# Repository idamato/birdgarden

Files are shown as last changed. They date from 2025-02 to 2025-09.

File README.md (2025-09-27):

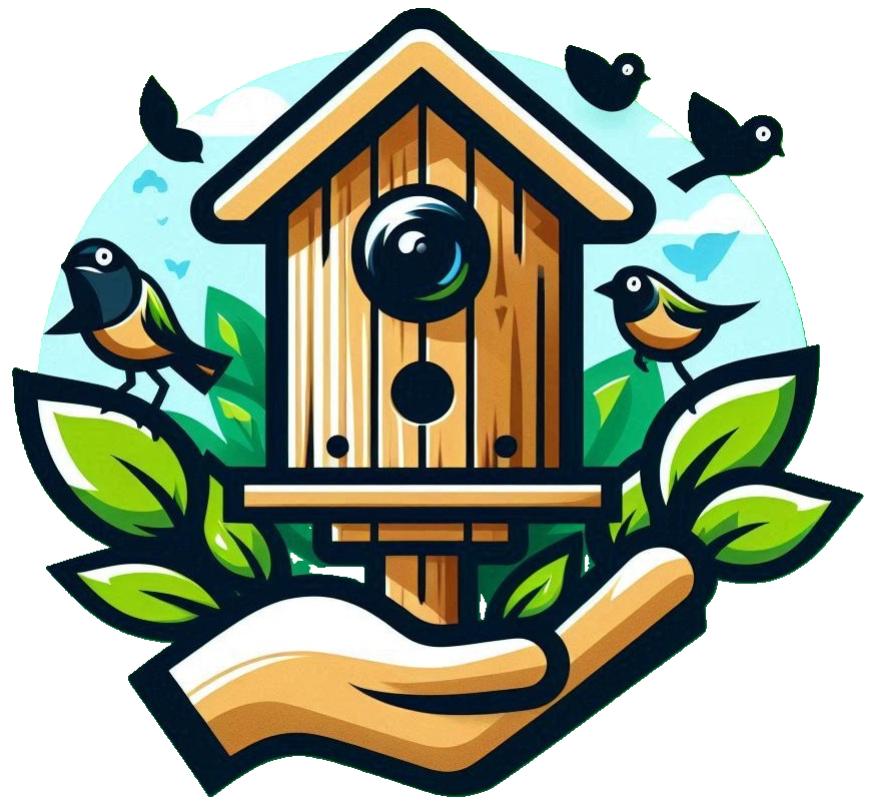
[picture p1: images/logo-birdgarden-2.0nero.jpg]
Birgaren 2.0 Logo


# Birdgarden 2.0

Progetto realizzato a cura dei soci di il faro d'argento APS [www.webradiofaro.it](www.webradiofaro.it)

Il progetto Birdgarden 2.0 mira alla realizzazione di una casetta/nido o mangiatoia per gli uccellini, monitorata attraverso una camera ed un microfono nascosti che metterà a disposizione su internet i dati rilevati, l’audio e le foto scattate nei momenti in cui viene occupata.

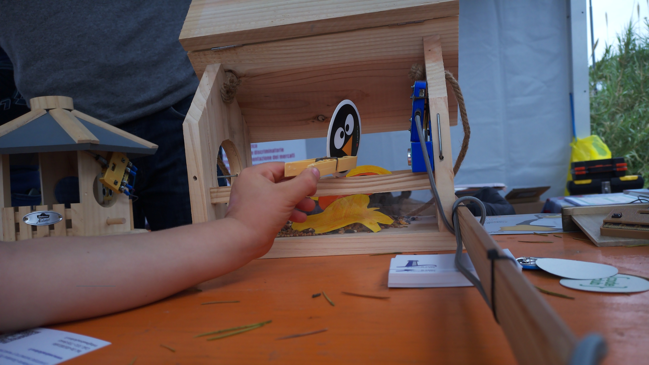
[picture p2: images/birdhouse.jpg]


Per l'inizializzazione del dispositivo al primo utilizzo sono necessarie alcune attività per le quali è necessario collegare al dispositivo un monitor o TV tramite il cavo HDMI ed una tastiera+mouse tramite il cavo USB aggiuntivo.

 In alternativa è possibile configurare il sistema raspberry attraverso una connessione seriale, per mezzo di un cavo del tipo USB-to-SERIAL con chip PL2303, facendo attenzione al fatto che sia utilizzabile con la tensione dei 3V dei GPIO del Raspberry.

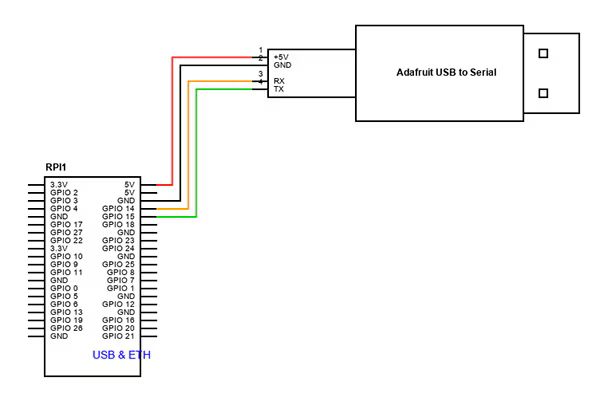
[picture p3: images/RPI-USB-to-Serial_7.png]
RPI-Serial
 

Per il collegamento attraverso la porta seriale è necessario abilitarne l'accesso nel file config.txt inserendo la seguente riga: enable_uart=1

Nelle versioni più recenti del sistema Raspian OS non esiste un utente preconfigurato con cui eseguire il login tuttavia tramie il software Raspberry Pi Imager è possibile definire le principali configurazioni prima ancora del primo avvio, cosa che in questo progetto abbiamo fatto per voi.

Per i sistemi Linux Debian è sufficiente digitare il comando
~~~
sudo apt install rpi-imager
~~~ 

Mentre per Windows si può scaricare l'installer direttamente dal sito [raspberrypi.com](https://www.raspberrypi.com/software/)]

Per il collegamento via seriale abbiamo utilizzato il comando: tio /dev/ttyUSB0, dopo aver verificato che il device ttyUSB0 fosse correttamente associato al cavo USB-to-serial inserito, per mezzo del comando: sudo dmesg, che fornisce le seguenti informazioni:

~~~bash
[ 7849.113480] usb 1-2: new full-speed USB device number 13 using xhci_hcd
[ 7849.240467] usb 1-2: New USB device found, idVendor=067b, idProduct=2303, bcdDevice= 4.00
[ 7849.240514] usb 1-2: New USB device strings: Mfr=1, Product=2, SerialNumber=0
[ 7849.240537] usb 1-2: Product: USB-Serial Controller
[ 7849.240555] usb 1-2: Manufacturer: Prolific Technology Inc.
[ 7849.245418] pl2303 1-2:1.0: pl2303 converter detected
[ 7849.248483] usb 1-2: pl2303 converter now attached to **ttyUSB0**
~~~

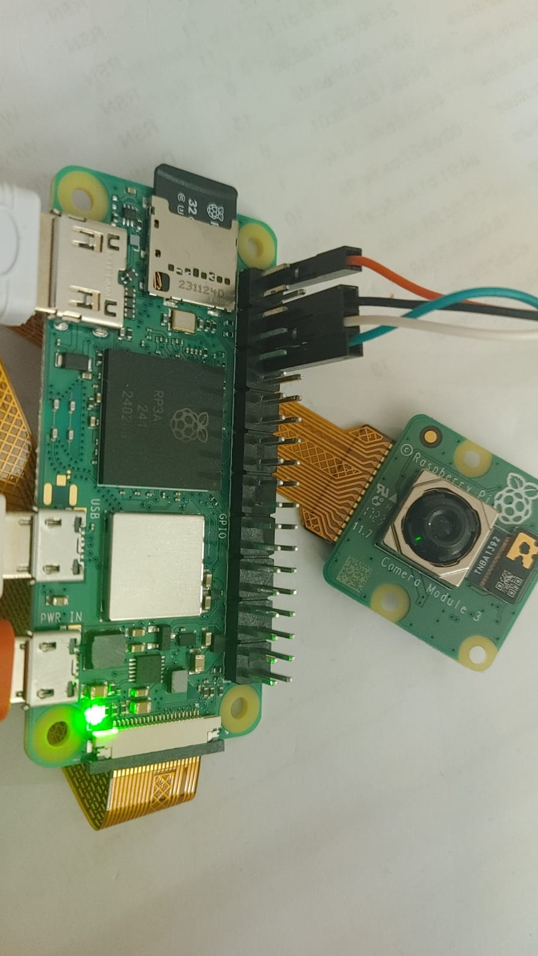
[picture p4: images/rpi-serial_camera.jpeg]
Rpi-Serial-Camera


## Configurazione iniziale

Tenete a mente che durante il primo avvio il sistema opera delle configurazioni automatiche ed esegue anche un riavvio automatico, quindi impiega necessariamente più tempo a partire rispetto ad una normale procedura, come accadrà in seguito. Se tutto è andato a buon fine avrete a video la richiesta di login, oppure il desktop del sistema Raspian OS, se avete installato la versione desktop. In tal caso potrete aprire una finestra terminale per proseguire con le attività di configurazione descritte nel seguito.

Eseguire le operazioni seguenti:

- eseguire il login con username e password impostati (l'importante è che la home directory si chiami /home/ilfarodargento)
- eseguire l’aggiornamento di RPI Os con i comandi:

```bash
$ sudo -s 
$ export DEBIAN_FRONTEND=noninteractive
$ apt update -y \
  && apt upgrade -y \
  && apt full-upgrade -y
```
> [!NOTE] 
> Questo task può durare anche 30 minuti

Terminato l'operazione è consigliato effettuare il riavvio

Procedere all'installazione delle dipendenze

~~~bash
$ sudo apt update && \
  sudo apt install -y python3-picamera2\
                      ffmpeg \
                      git \
                      python3-serial \
~~~

Terminata l'installazione effettuare il clone di questo repository all'interno della RPi

~~~bash
$ git clone https://github.com/idamato/birdgarden/
~~~

e procedere all'installazione

~~~
$ cd birdgarden
$ sudo bash install_rpi.sh
~~~

- modificare username e password e identificativo TAG con la CPUID nel file wordpress_playground.py secondo le indicazioni ricevute al momento dell'adesione al progetto. (Viene creato un account all'interno del portale Birdgarden 2.0 con le credenziali per la pubblicazione delle foto/video dal dispositivo)
- creare il link simbolico al file photo.service di avvio del servizio al boot:
  sudo cp /home/ilfarodargento/birdgarden/photo.service /lib/systemd/system/photo.service ;
  sudo systemctl enable photo.service ;
  sudo systemctl start photo.service (comando per l'avvio manuale) ;
  sudo journalctl --unit=photo.service (per verificare il log delle esecuzioni precedenti)
- configurare il comando a tempo (crontab -e) aggiungendo in fondo la seguente riga:
  - `30 * * * * /home/ilfarodargento/birdgarden/sendphoto.sh >> /home/ilfarodargento/logs/cron.log 2>&1`
- dalla /home/ilfarodargento creare le directory per i log e per le foto da spedire e spedite con: `mkdir logs departures sent`
- per la rotazione dei log installiamo il file di configurazione: `sudo cp birdgarden/birdgarden /etc/logrotate.d/`
- esegure il test del focus della fotocamera sulla vostra installazione eseguendo il comando: `python3 test-camera-focus.py`; tenete presente che se state utilizzando il terminale senza grafica dovrete prima modificare lo script impostando la preview a False.
- collegare anche il dispositivo micro:bit caricandovi il codice `serial_data_logger.py` tramite il sito [Makecode](makecode.microbit.org).
- Se si desidera modificare la configurazione del WiFi si può procedere nel modo seguente: eseguire il comando: `sudo nmtui`, ed abilitare la rete wifi di interesse.

Se si desidera modificare la configurazione del WiFi si può procedere nel modo seguente:
- eseguire il comando: sudo nmtui, ed abilitare la rete wifi di interesse

Ci sono inoltre una serie di aspetti di configurazione che sono stati curati all'interno del portale https://www.webradiofaro.it/birdgarden/ che utilizza Wordpress.
In particolare deve essere creato un utente/ruolo specifico associato al dispositivo in modo che nello stesso portale possano concorrere le pubblicazioni di tutti i dispositivi.
Oltre all'utente deve essere anche creata una chiave applicativa legata all'applicazione Birdgarden e con essa si avranno le credenziali da inserire nello scirpt Python per l'invio dati.

-

# Testing 

>[!WARNING]
Work in progress

Per RPi  ARMv7
```bash
podman run -it  --volume $PWD:/src --platform=linux/arm/7 dtcooper/raspberrypi-os:bookworm
```

Per RPi ARM64

```bash
podman run -it  --volume $PWD:/src --platform=linux/arm64 dtcooper/raspberrypi-os:bookworm
```

e poi 

~~~bash
# cd /src
# bash install_rpi.sh
~~~

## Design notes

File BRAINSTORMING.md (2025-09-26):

This is a brainstorming file where to put your immagination about the possible future evolution of this project.

1) AI adoption
    a) AI hardware selection
    b) AI engine selection
    c) AI training needed?

2) Mesh network configuration

3) Solar panel integration

4) Is it worth to have the Micro:bit out of this project, or there could be some hidden benefits?
    a) How do you think about having Micro:bit as an optional device? Wireless connected via serial-bluethoot to the Raspberry, only to issue command to this one? 
    b) Is it worth to use PIR sensor instead of the SONAR one, and connect it directly to the Raspberry?

5) Are terminal based (text) images possible to inject as AI training? ASCII Art convertion could help reduce the complexity of the AI model and calculations?

6) Ham radio SSTV mode as a new option for sending images
    a) There is a Python module which enable image transformation into wav files
       Some instruction require installation of specific libraries, check inside GitHub repository of every library or software.
       The following may be needed: sudo apt install libgd-dev libmagic-dev
       a.1)
           The generated audio can be sent as a modulated FM signal over the antenna using PiFM 
           git clone https://github.com/dnet/pySSTV
           cd pySSTV ; python3 ./setup.y build ; sudo python3 ./setup.py install
           cd <where images are> ; python3 -m pysstv --mode MartinM2 --resize image.png output.wav 
           an image file of 35Kb result in an audio wav file of about 5.5 Mb.
       a.2) Raspberry pi is able to send FM mofulation as RF via a small antenna connected to the GPIO4
       git clone https://github.com/F5OEO/rpitx
       cd rpitx ; ./install.sh (the compile process somehow fail to compile some programs but we need the pifmrds which is orrectly available)
       reboot
       sudo ./pifmrds -freq 76 -audio /home/ilfarodargento/sent/pettirosso-inverno.wav
    b) per trasmettere a frequenze differenti dalla FM commerciale, come ad esempio a 433 Mhz la procedura è differente:
       si usa imagemagik per trasformare l'immagine in un formato adatto con il comando seguente
       convert <input> -resize '320x256^' -gravity center -extent 320x256 -depth 8 <output>.rgb
       poi si converte il file .rgb in formato .ft con il comando seguente
       pisstv <input>.rgb <output>.ft
       ed infine si avvia la trasmissione alla frequenza desiderata, il range è da pochi kHz fino a 700 Mhz, con il comandi seguente
       sudo rpitx -m RF -i <input>.ft -f <frequency in KHz>
       
...possibile utilizzo anche per le radiosonde che potrebbero inviare immagini
        
script funzionanti:

ilfarodargento@birdgarden:~/birdgarden $ cat encoderMicroFAX.py
from PIL import Image
import numpy as np
import wave
import struct
import math
import serial
import threading
import queue
import time

# Parametri SSTV semplificati
INPUT_IMAGE = "../images/Pettirosso.jpg"
CONVERTED_IMAGE = "../images/microfax_pettirosso.jpg"
OUTPUT_WAVE = "../images/microfax_signora.wav"
WIDTH, HEIGHT = 64, 64
GRAY_MIN, GRAY_MAX = 0, 255
FREQ_MIN, FREQ_MAX = 1500, 2300
PIXEL_DURATION = 0.05
SYNC_FREQ = 1200
SYNC_DURATION = 0.2
EOL_FREQ = 300          # Frequenza speciale fine riga
EOL_DURATION = 0.05     # Durata tono fine riga
SAMPLE_RATE = 44100
samples = 0

# Imposta la connessione seriale
ser_micro = serial.Serial('/dev/ttyACM0', 115200, timeout=1)
if not ser_micro:
    logging.info('microbit not found')

def load_and_convert_image(path):
    img = Image.open(path).convert('L')
    img = img.resize((WIDTH, HEIGHT), Image.NEAREST)
    img.save(CONVERTED_IMAGE)
    return np.array(img)

def gray_to_freq(gray):
    micro_freq = FREQ_MIN + int((gray / 255) * (FREQ_MAX - FREQ_MIN))
    global samples
    samples += 1
    print(samples,micro_freq)
    ser_micro.write(str(micro_freq).encode('utf-8'))
    time.sleep(0.1)  # breve pausa per evitare collisioni
    return micro_freq

def generate_tone(freq, duration):
    return [math.sin(2 * math.pi * freq * i / SAMPLE_RATE) for i in range(int(SAMPLE_RATE * duration))]

def save_wave(filename, data):
    with wave.open(filename, 'w') as wav:
        wav.setnchannels(1)
        wav.setsampwidth(2)
        wav.setframerate(SAMPLE_RATE)
        for s in data:
            val = max(-1.0, min(1.0, s))
            wav.writeframes(struct.pack('<h', int(val * 32767)))

def generate_sstv_audio(gray_array):
    audio_data = []

    for row in gray_array:
        audio_data += generate_tone(SYNC_FREQ, SYNC_DURATION) # Sync
        for pixel in row:
            freq = gray_to_freq(pixel)
            audio_data += generate_tone(freq, PIXEL_DURATION)
        audio_data += generate_tone(EOL_FREQ, EOL_DURATION) # Fine riga

    return audio_data

# Processo completo
image_path = INPUT_IMAGE
gray_matrix = load_and_convert_image(image_path)
audio = generate_sstv_audio(gray_matrix)
#save_wave(OUTPUT_WAVE, audio)

print("WAV Audio microFAX con tono di fine riga salvato")

ilfarodargento@birdgarden:~ $ cat receiver.py
import serial
import time
import numpy as np
import wave
import struct
import math
from PIL import Image

# Parametri SSTV semplificati
CONVERTED_IMAGE = "microfax_grayscale.jpg"
OUTPUT_WAVE = "microfax_grayscale.wav"
WIDTH, HEIGHT = 64, 64
GRAY_MIN, GRAY_MAX = 0, 255
FREQ_MIN, FREQ_MAX = 1500, 2300
PIXEL_DURATION = 0.05
SYNC_FREQ = 1200
SYNC_DURATION = 0.2
EOL_FREQ = 300          # Frequenza speciale fine riga
EOL_DURATION = 0.05     # Durata tono fine riga
SAMPLE_RATE = 44100
count = 0

ser = serial.Serial('/dev/ttyACM0', 115200)
time.sleep(2)

def freq_to_gray(freq):
    gray = int(((freq - FREQ_MIN) / (FREQ_MAX - FREQ_MIN)) * 255)
    return gray

matrice_grigi = [[0 for x in range(64)] for y in range(64)]

for y in range(64):
    for x in range(64):
        line = ser.read(4).decode().strip()
        try:
            freq = int(line)
            gray = freq_to_gray(freq)
            count = count + 1
            print(count,y,x,gray)
        except ValueError:
            gray = 0
        matrice_grigi[y][x] = gray

# Converti la matrice in un array NumPy
array = np.array(matrice_grigi, dtype=np.uint8)

# Crea l'immagine in scala di grigi
immagine = Image.fromarray(array, mode='L')

# Salva come JPG
immagine.save("immagine.jpg")

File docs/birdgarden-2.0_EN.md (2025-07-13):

**Birdgarden 2.0** is an educational initiative that merges a passion for nature — particularly birdlife — with the potential of technology, the ethos of open source, and a commitment to scientific outreach. Born out of the desire to promote urban ecology through accessible tools, the project seeks to bring citizens, students, and no profit associations closer to environmental monitoring via a technological device that is both simple and powerful.

At the heart of the initiative is the creation of birdhouses or feeders — even 3D-printed if preferred — equipped with a camera and embedded sensors. These components are discreetly integrated into the structure and serve to collect environmental data, images, and video, documenting birds activity in a non-invasive way. The gathered content, following an approval process, may be published on a dedicated portal (https://www.webradiofaro.it/birdgarden/), promoting community participation and public awareness. To ensure complete energy autonomy, the birdhouses are powered by solar panels coupled with a power bank, making installation feasible even in remote natural areas or urban locations without access to the electrical grid.

The foundation of Birdgarden 2.0 lies in the desire to combine a love for nature, DIY craftsmanship, and programming with a collaborative educational approach. The data generated by Birdgarden installations can serve as an informational basis for naturalistic studies and multidisciplinary learning activities. In this sense, the project also functions as a tool for designing educational pathways that foster open source culture and STEM competencies within middle and high schools, engaging students aged 13 to 19.

The initiative embodies a spirit of public engagement and community participation, serving as a self-financing model for the leading organization, Il faro d’argento APS (https://www.webradiofaro.it). Birdhouses may be built independently or purchased through outlets such as the LIPU (https://www.lipu.it), strengthening the network of awareness surrounding urban biodiversity and helping gather donations to support related efforts.

From a technological perspective, the system integrates a Raspberry Pi microcomputer with a camera module, accompanied by a Micro:bit microcontroller, and an ultrasonic sensor for detecting bird presence. The entire software ecosystem is developed in-house by project members and released as open source (https://github.com/idamato/birdgarden), offering the public free access to code, documentation, and assembly instructions. This open framework has enabled the activation of free workshops, such as those hosted by the Roma/Infernetto@SecondoSabato/ILFARO club through the CoderDojo network (https://codeclub.org).

Birdgarden 2.0 is supported by a group of environmentally minded technology enthusiasts collaborating with schools, local entities, and third-sector organizations. The project has been publicly showcased in various events, including Maker Faire (https://makerfairerome.eu) and Villaggio per la Terra (https://villaggioperlaterra.it) in Rome, engaging numerous participants and fostering an active community. Two editions of the STEM course have been held at I.C. Aristide Leonori (https://icleonori.edu.it) in Rome, targeting lower secondary students and culminating in the installation of a device.

Future developments include new functionalities designed in cooperation with the Italian Amateur Radio Association – Ostia Section (https://www.ariostia.it). Among these is the exploration of image transmission via FM SSTV radio technologies — the same used aboard the International Space Station — as well as low-power communication methods using Mesh networks and the LoRa protocol, allowing deployment in remote areas without Wi-Fi coverage.

Internal working groups are also investigating the use of artificial intelligence for automatic bird species recognition through audio and image analysis. This broadens the educational scope to include AI-related themes while enabling even more detailed biodiversity monitoring. Moreover, the project is well-suited to integration within Citizen Science initiatives, encouraging active public participation in image classification and validation of data produced by intelligent modules.

On the outreach front, Il faro d’argento APS is developing plug-and-play kits suitable for users with limited technical skills, thus expanding opportunities for public involvement. A dedicated school module has also been created to guide students and teachers through every project phase — from concept to programming, installation, and monitoring.

Numerous events, technical workshops, and training sessions — both online and in person — have helped disseminate the project to an increasingly broad audience. Although primarily focused on birds, Birdgarden 2.0 also considers extending monitoring to other small animals, thus expanding its ecological reach.

In a broader context, the initiative is aligned with themes of environmental sustainability and social impact. It encourages the use of birdhouses within urban reforestation and community gardening projects and is often accompanied by the creation of urban vegetable plots.

Ultimately, Birdgarden 2.0 aims to serve as an active element in Smart City development plans, contributing to the creation of more livable urban spaces that are mindful of biodiversity. In summary, what began as an educational and experimental initiative aspires to become a participatory environmental monitoring network capable of generating valuable scientific data, promoting technical and ecological knowledge, and inspiring citizens to care for and connect with urban ecosystems.

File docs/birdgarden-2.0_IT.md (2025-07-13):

**Birdgarden 2.0** rappresenta un'iniziativa didattica che coniuga la passione per la natura — in particolare per l'avifauna — con le potenzialità della tecnologia, la filosofia open source e l'impegno nella divulgazione scientifica. Nato dal desiderio di promuovere l'ecologia urbana attraverso strumenti accessibili, il progetto si propone di avvicinare cittadini, studenti e associazioni no profit al mondo del monitoraggio ambientale mediante un dispositivo tecnologico semplice ma potente.

Il cuore dell'iniziativa consiste nella realizzazione di casette-nido o mangiatoie per piccoli uccelli (anche stampate in 3D), dotate di una telecamera e di sensori, accuratamente occultati all’interno della struttura. Tali strumenti permettono di raccogliere dati ambientali, immagini e video, documentando le attività avifaunistiche in modo non invasivo. I contenuti acquisiti, superato un processo di approvazione, possono essere messi a disposizione della comunità scientifica e del pubblico attraverso un portale (https://www.webradiofaro.it/birdgarden/), favorendo così la partecipazione e la sensibilizzazione. Per garantire la completa autonomia energetica delle casette, si fa ricorso a pannelli solari abbinati a sistemi di accumulo, una strategia che consente l’installazione in aree naturali remote o urbane non servite da rete elettrica. 

Alla base del progetto si pone la volontà di fondere l'amore per la natura, il fai-da-te e la programmazione con un approccio educativo e collaborativo. I dati raccolti dalle installazioni di Birdgarden 2.0 possono fungere da base informativa per studi naturalistici e attività didattiche multidisciplinari. In tal senso, il progetto si configura anche come strumento per la costruzione di percorsi formativi mirati alla diffusione della cultura open source e delle competenze STEM all’interno delle scuole secondarie di primo e secondo grado, coinvolgendo alunni dai 13 ai 19 anni.

Il progetto è animato da uno spirito divulgativo e partecipativo, rappresenta un modello di autofinanziamento per l’associazione promotrice Il faro d’argento APS (https://www.webradiofaro.it). Le casette possono essere realizzate in proprio o acquistate anche presso il sito della LIPU (https://www.lipu.it), rafforzando la rete di sensibilizzazione verso la tutela della biodiversità urbana e favorendo la raccolta di donazioni a sostegno delle attività.

Dal punto di vista tecnologico, il sistema integra un microcomputer Raspberry Pi con modulo fotocamera, accompagnato da un microcontrollore Micro:bit, cui si aggiunge un sensore a ultrasuoni per il rilevamento della presenza degli uccelli. L'intero ecosistema software è sviluppato direttamente dai soci promotori e rilasciato in modalità open source (https://github.com/idamato/birdgarden), offrendo al pubblico accesso libero a codice, documentazione e istruzioni di montaggio. Questo approccio ha consentito l’attivazione di laboratori gratuiti, come quelli condotti all’interno del circuito CoderDojo al club Roma/Infernetto@SecondoSabato/ILFARO (https://codeclub.org).

Birdgarden 2.0 è sostenuto da un gruppo di cittadini appassionati di natura e tecnologia, in collaborazione con scuole, enti locali e organizzazioni del terzo settore. Il progetto è stato presentato pubblicamente in diversi eventi, tra cui la Maker Faire (https://makerfairerome.eu)e il Villaggio per la Terra (https://villaggioperlaterra.it) a Roma, coinvolgendo numerose persone e dando vita a una vera e propria comunità attiva. Presso l'I.C. Aristide Leonori (https://icleonori.edu.it) di Roma si sono tenute due edizioni del corso STEM, rivolto ad alunni della prima media, che si sono concluse con una installazione del dispositivo.

Nel quadro delle evoluzioni future, si stanno progettando nuove funzionalità con il contributo dell'Associazione Radioamatori Italiani – Sezione di Ostia (https://www.ariostia.it). Tra queste, rientra lo studio di soluzioni trasmissive delle immagini basate sull’utilizzo di tecnologie radio FM SSTV, le stesse utilizzate dalla ISS la stazione spaziale internazionale, così come soluzioni a basso consumo energetico basate su reti Mesh e protocollo LoRa, che permettono l'installazione anche in zone isolate prive di copertura Wi-Fi.

Dei gruppi di studio interni all'associazione stanno affrontando possibili estensioni che considerano l'utilizzo dell’intelligenza artificiale per il riconoscimento automatico delle specie avifaunistiche, attraverso l’analisi dei suoni e delle immagini raccolte. Ciò allarga lo spettro didattico ai temi dell'AI e consente un monitoraggio ancora più dettagliato della biodiversità locale, il progetto si presta inoltre a essere integrato in iniziative di Citizen Science, incentivando la partecipazione attiva di cittadini nella classificazione delle immagini e nella convalida dei dati forniti dai moduli intelligenti.

Sul versante divulgativo, l'associazione il faro d'argento APS sta progettando kit plug-and-play, assemblabili anche da utenti senza conoscenze tecniche avanzate, promuovendo così una partecipazione più ampia. Inoltre, è stato elaborato un modulo didattico specifico per le scuole, in grado di guidare studenti e insegnanti attraverso tutte le fasi del progetto: dall'ideazione alla programmazione, fino all’installazione e al monitoraggio.

Non mancano gli eventi, workshop tecnici e momenti di formazione in presenza e online, attraverso i quali il progetto viene condiviso con un pubblico sempre più vasto. Pur concentrandosi principalmente sugli uccelli, Birdgarden 2.0 contempla la possibilità di estendere il monitoraggio ad altri piccoli animali, ampliando il raggio d’azione verso nuovi ecosistemi.

In una prospettiva più ampia, il progetto si collega a tematiche di sostenibilità ambientale e impatto sociale. È incentivato un utilizzo delle casette con iniziative di riforestazione urbana e di agricoltura cittadina, nonché associata alla presenza di orti urbani. 

Infine, Birdgarden 2.0 intende porsi come elemento attivo nei progetti di Smart City, contribuendo alla creazione di spazi urbani più vivibili e sensibili alla biodiversità. In sintesi, da progetto educativo e sperimentale, Birdgarden 2.0 aspira a diventare una rete di monitoraggio ambientale partecipativa, capace di generare dati scientifici rilevanti, promuovere la cultura tecnica e ambientale, e avvicinare la cittadinanza al rispetto e alla cura degli ecosistemi urbani.

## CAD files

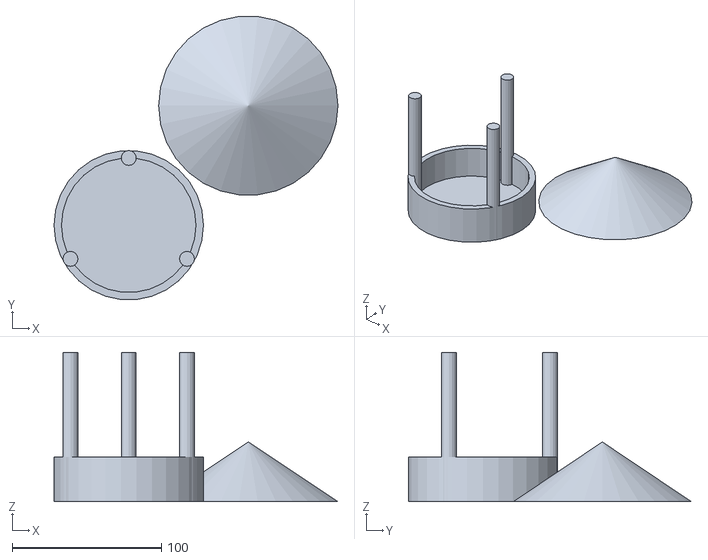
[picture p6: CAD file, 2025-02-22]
drawings/mangiatoia dupezzi.stl
190.0 x 189.4 x 100.0

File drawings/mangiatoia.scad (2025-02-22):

  //Parametri
  base_raggio = 100;
  base_altezza = 50;
  base_spessoreb = 10;
  base_b = base_raggio - base_spessoreb;
  colonna_altezza = 150;
  colonna_n = 3;
  colonna_raggio = 10;
  tetto_raggio = base_raggio + (base_raggio*20/100);    
  tetto_altezza = 80;  
  sfera_raggio = tetto_raggio - (tetto_raggio*30/100);

module mangiatoia()
{
  //Disegno della base
  translate([0, 0, -120]) {
    difference() {
      cylinder(h = base_altezza, r = base_raggio);
      translate([0, 0, colonna_raggio]) cylinder(h = base_altezza, r = base_b);
      //translate([base_raggio, 0, 35]) cube(50, center = true);
    }
    // Disegno delle colonne
    for (i = [0:(colonna_n-1)]) {
      echo(360*i/colonna_n, sin(360*i/colonna_n)*base_b, cos(360*i/colonna_n)*base_b);
      translate([sin(360*i/colonna_n)*base_b, cos(360*i/colonna_n)*base_b, 0 ])
        cylinder(h = colonna_altezza, r=colonna_raggio);
    }
    // Disegno del tetto
    difference() {
    translate([0, 0, colonna_altezza])
      cylinder(h = tetto_altezza, r1 = tetto_raggio, r2 = 0);
    translate([0, 0, colonna_altezza - sfera_raggio/2])
      sphere(sfera_raggio);
    }
  }
}

echo(version=version());

rotate(a=[0,180,0]) mangiatoia();

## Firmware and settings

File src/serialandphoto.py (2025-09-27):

#!/usr/bin/python

from time import sleep
from picamera2 import Picamera2
from libcamera import controls
import serial
import os
# from gpiozero import LED
# from gpiozero import MotionSensor

# funzione per la gestione della lettura dei dati dalla porta seriale
porta = '/dev/ttyACM0'
baudrate = 115200

def leggi_dati_seriale(porta, baudrate):
    while True:
        try:
            # Apertura della connessione seriale
            with serial.Serial(porta, baudrate, timeout=1) as ser:
                # print(f"Connesso a {porta} a {baudrate} baud.")
                while True:
                    # Lettura dei dati
                    dati = ser.readline().decode('utf-8').rstrip()
                    if dati:
                        return dati

        except serial.SerialException as e:
            # Gestione errore di connessione
            print(f"Errore di connessione: {e}")
            print("Tentativo di riconnessione tra 5 minuti...")
            sleep(300)  # Attendi 5 minuti e riprova

# ser = serial.Serial('/dev/ttyACM0', 115200, timeout=1)
# la funzione verifica se è arrivato il comando di shutdown
def verifica_halt(array):
    if len(array) == 5 and all(elemento == '0' for elemento in array):
        return True
    return False

# funzione che impartisce il comando di chiusura del sistema
def arresta_sistema():
    try:
        # Esegue il comando di halt
        os.system("sudo shutdown -h now")
    except Exception as e:
        print(f"Si è verificato un errore: {e}")

# inizializza la fotocamera
camera = Picamera2()
# l'anodo del LED (gamba lunga) è collegato al GPIO 17
# fra il catodo (gamba corta) e GROUND è necessario collegare una resistenza di almeno 100 ohm
# flash_led = LED(17)
# nel caso di utilizzo di motion sensor
# sensor = MotionSensor(14)

id = 0
# capture_config = camera.create_still_configuration(main={"size":(1920, 1080)}, lores={"size":(640,480)})

# imposta il modo autofocus nel continuo
# camera.set_controls({"AfMode": controls.AfModeEnum.Continuous})

# imposta il modo autofocus con alta velocità
#camera.set_controls({"AfMode": controls.AfModeEnum.Continuous, "AfSpeed": controls.AfSpeedEnum.Fast})

# imposta il focus in modalità manuale a 10cm, il minimo
# camera.set_controls({"AfMode": controls.AfModeEnum.Manual, "LensPosition": 10.0})

# imposta la cattura di tre immagini consecutive
# camera.start_and_capture_files("fastfocus{:d}.jpg", num_files=3, delay=0.5)

# capture_config = camera.create_still_configuration()
# camera.configure(capture_config)

print ("Hello this is the start!")

while True:
    # rcv = ser.readline()
    # cmd = rcv.decode('utf-8').rstrip()
    cmd = leggi_dati_seriale(porta, baudrate)
    values = cmd.split(',')
    print(values)
    if len(values) == 5: 
      luce, temperatura, audio, pin0, sonar = [int(value) for value in values]
      print(luce, temperatura, audio, pin0, sonar)
      if verifica_halt(values):
         # Execute the sudo halt command
         print('devo arrestare il sistema')
         arresta_sistema()
      if pin0:
        id += 1
        print('fare foto!')
        camera.start()
        # capture_config = camera.create_still_configuration(main={"size":(1920, 1080)}, lores={"size":(640,480)})
        capture_config = camera.create_still_configuration()
        filename = "/home/ilfarodargento/departures/" + str(id) + "_" + str(luce) + "_" + str(temperatura) + "_" + str(audio) + "_" + str(sonar)
        # flash_led.on()
        camera.set_controls({"AfMode": controls.AfModeEnum.Continuous, "AfSpeed": controls.AfSpeedEnum.Fast})
        # attendo un secondo per la messa a fuoco
        sleep(1)
        # esegue la foto
        camera.switch_mode_and_capture_file(capture_config, filename + ".jpg")
        # in caso di video
        camera.start_and_record_video(filename + ".mp4", duration=15)
        # flash_led.off()
        camera.stop()
        print('missione compiuta: ', filename)
      # sleep(1)
done

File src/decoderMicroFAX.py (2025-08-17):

import numpy as np
import matplotlib.pyplot as plt
import wave

# Parametri del segnale
INPUT_WAVE = "C:/Users/taotr/Downloads/microfax_signora.wav"
OUTPUT_IMAGE = "C:/Users/taotr/Downloads/microfax_signora.png"
PIXEL_DURATION = 0.05
SAMPLE_RATE = 44100
FREQS = np.linspace(1500, 2300, 256)      # Miglior mappatura pixel
END_OF_LINE_FREQ = 300                    # Tono fine riga
EOL_TOLERANCE = 15                        # ± tolleranza Hz per il riconoscimento

def load_audio(filename):
    with wave.open(filename, 'rb') as wf:
        frames = wf.readframes(wf.getnframes())
        signal = np.frombuffer(frames, dtype=np.int16)
        return signal

def decode(signal, width):
    chunk_size = int(SAMPLE_RATE * PIXEL_DURATION)
    num_chunks = len(signal) // chunk_size

    image = []
    row = []

    for i in range(num_chunks):
        start = i * chunk_size
        end = start + chunk_size
        chunk = signal[start:end]

        # FFT → Frequenza dominante
        fft = np.abs(np.fft.fft(chunk))[:len(chunk)//2]
        freqs_axis = np.fft.fftfreq(len(chunk), d=1/SAMPLE_RATE)[:len(chunk)//2]
        dominant_freq = freqs_axis[np.argmax(fft)]

        if abs(dominant_freq - END_OF_LINE_FREQ) <= EOL_TOLERANCE:
            # È il tono di fine riga → salva riga e resetta
            if row:
                image.append(row)
                row = []
        else:
            index = np.argmin(np.abs(FREQS - dominant_freq))
            row.append(index)

    # 🔚 Aggiungi ultima riga se non terminata
    if row:
        image.append(row)

    return np.array(image)

def visualize(pixels, filename):
    plt.imshow(pixels, cmap='gray', interpolation='nearest')
    plt.axis('off')
    plt.savefig(filename, bbox_inches='tight', pad_inches=0)
    plt.close()
    print(f"Immagine salvata come: {filename}")
    print("Dimensione:", pixels.shape)

# Esempio d’uso
if __name__ == '__main__':
    audio = load_audio(INPUT_WAVE)
    pixel_matrix = decode(audio, width=64)
    visualize(pixel_matrix, filename=OUTPUT_IMAGE)

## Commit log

2024-11-07 Versione iniziale
    Utilizzata alla Maker Faire di Roma
2024-12-19 Update serial_data_logger.py
    ottimizzazioni per il consumo energetico
2024-12-19 Update serialandphoto.py
    inseriti i commenti per la gestione del led
2025-02-22 modello mangiatoia per stampa 3D
    [mangiatoia dupezzi.stl, mangiatoia.scad]
2025-03-19 Commentato il sudocrontab.txt
2025-03-19 commit devel1 prima volta
2025-04-01 modificato il testo
2025-04-01 ottimizzato il processo di lettura da porta seriale e di spedizione delle foto
2025-04-05 Update sendphoto.sh
    migliorato il controllo di doppia esecuzione
2025-04-09 Update serialandphoto.py
    modifiche alle funzioni di halt
2025-08-30 Update BRAINSTORMING.md
    aggiunto codice di prova
2025-08-31 Update serial_data_logger.py
    aggiornamento button A
2025-09-10 Project Reorg
    [mangiatoia dupezzi.stl, mangiatoia.scad]
2025-10-09 Update sendphoto.sh
    aggiunto il monitoraggio
2025-11-17 ensor info and example
    Added details about the sensor's maximum resolution and HDR limitations, along with an example code snippet for capturing images using Picamera2.
2025-12-28 Refactor button press handlers and add maxdist
2025-12-31 Fix filename construction in serialandphoto.py
    [serialandphoto.py]
2025-12-31 Fix filename construction in wordpress_playground.py
    [wordpress_playground.py]
2026-03-12 Enhance README with USB connection and service setup
    Added instructions for USB connection setup and service configuration for Raspberry Pi.
2026-03-26 Clarify comments in serialandphoto.py
    Updated comments to clarify the purpose of the serial data reading function and LED connection.
2026-03-27 Add documentation link for camera module
    Added documentation link for Raspberry Pi Camera Module 2.
2026-03-30 Distance measurement script for Raspberry Pi without the micro:bit
    testing Sonar sensor connected directly to the Raspberry pi zero
2026-03-30 A simplified version of serialandphoto.py without micro:bit
    we can connect the sonar sensor directly to the Raspberry but we miss the micro:bit sensor data... at your preference
2026-04-06 Some Raspberry Pi Zero 2W specific photo with GPIO Pinout
    GPIO Pinout
    Dimensions
    Mechanical drawing
    Components (front and rear)
2026-05-03 Add files via upload
    schema di collegamento senza microçbit con partitore di tensione
2026-10-21 Aggiornato il codice e la documentazione per AI e LoRa
2026-11-03 modifica di test sul branch
